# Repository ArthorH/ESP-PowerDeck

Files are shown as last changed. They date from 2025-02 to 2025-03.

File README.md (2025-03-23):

# ESP PowerDeck
Versitale development board for ESP32-S3 microcontroller
PowerDeckRender
## Project Status: **Ongoing**  
**Design** ✅ — **Fabrication** ✅ — **Assembly** ✅ — **Bringup** ⏳ — **Testing** ⏳  
## Key technologies:
&nbsp;&nbsp;&nbsp;&nbsp; &nbsp;&nbsp;&nbsp;&nbsp; &nbsp;&nbsp;&nbsp;&nbsp; &nbsp;&nbsp;&nbsp;&nbsp;
## Who it's for

Want to play with robotics? Maybe you have a cool IoT project in mind? You don't want to hassle with assembling development modules or soldering jumper cables, and jump straight into controlling serious hardware—not just LEDs on a breadboard?


#### Power deck is for you! 
&nbsp;&nbsp;&nbsp;&nbsp; &nbsp;&nbsp;&nbsp;&nbsp;
# Features
- 60W Power delivery input
- High power 5V and 3.3V line outputs
- 3 Channel H-Bridge power output stage with "SafeMode" and to 43W single channel H-Bridge output
- I2C current feedback for H-Bridges
- WS2812 and servo otputs
- Built in UART bridge
- Built in USB 2.0 Hub for ESP32 OTG
- UVLO OVLO protection for barrel jack psu

# Block Diagram:
A

# Usage:
It can drive anything from simple DC motors and Steppers:
izqkav0x

To driving bldc motors using advanced FOC alghoritms:
obraz

Also last but not least IoT projects are also possible:
obraz

# Author
Artem Horiunov
# License 
CERN-OHL-P V2

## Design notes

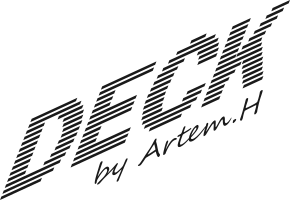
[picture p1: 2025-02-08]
PCB source/Doc/Silkscreen.png

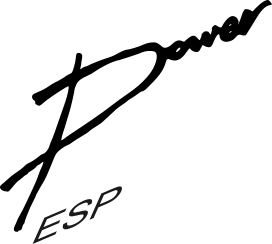
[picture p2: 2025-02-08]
PCB source/Doc/Copper.png

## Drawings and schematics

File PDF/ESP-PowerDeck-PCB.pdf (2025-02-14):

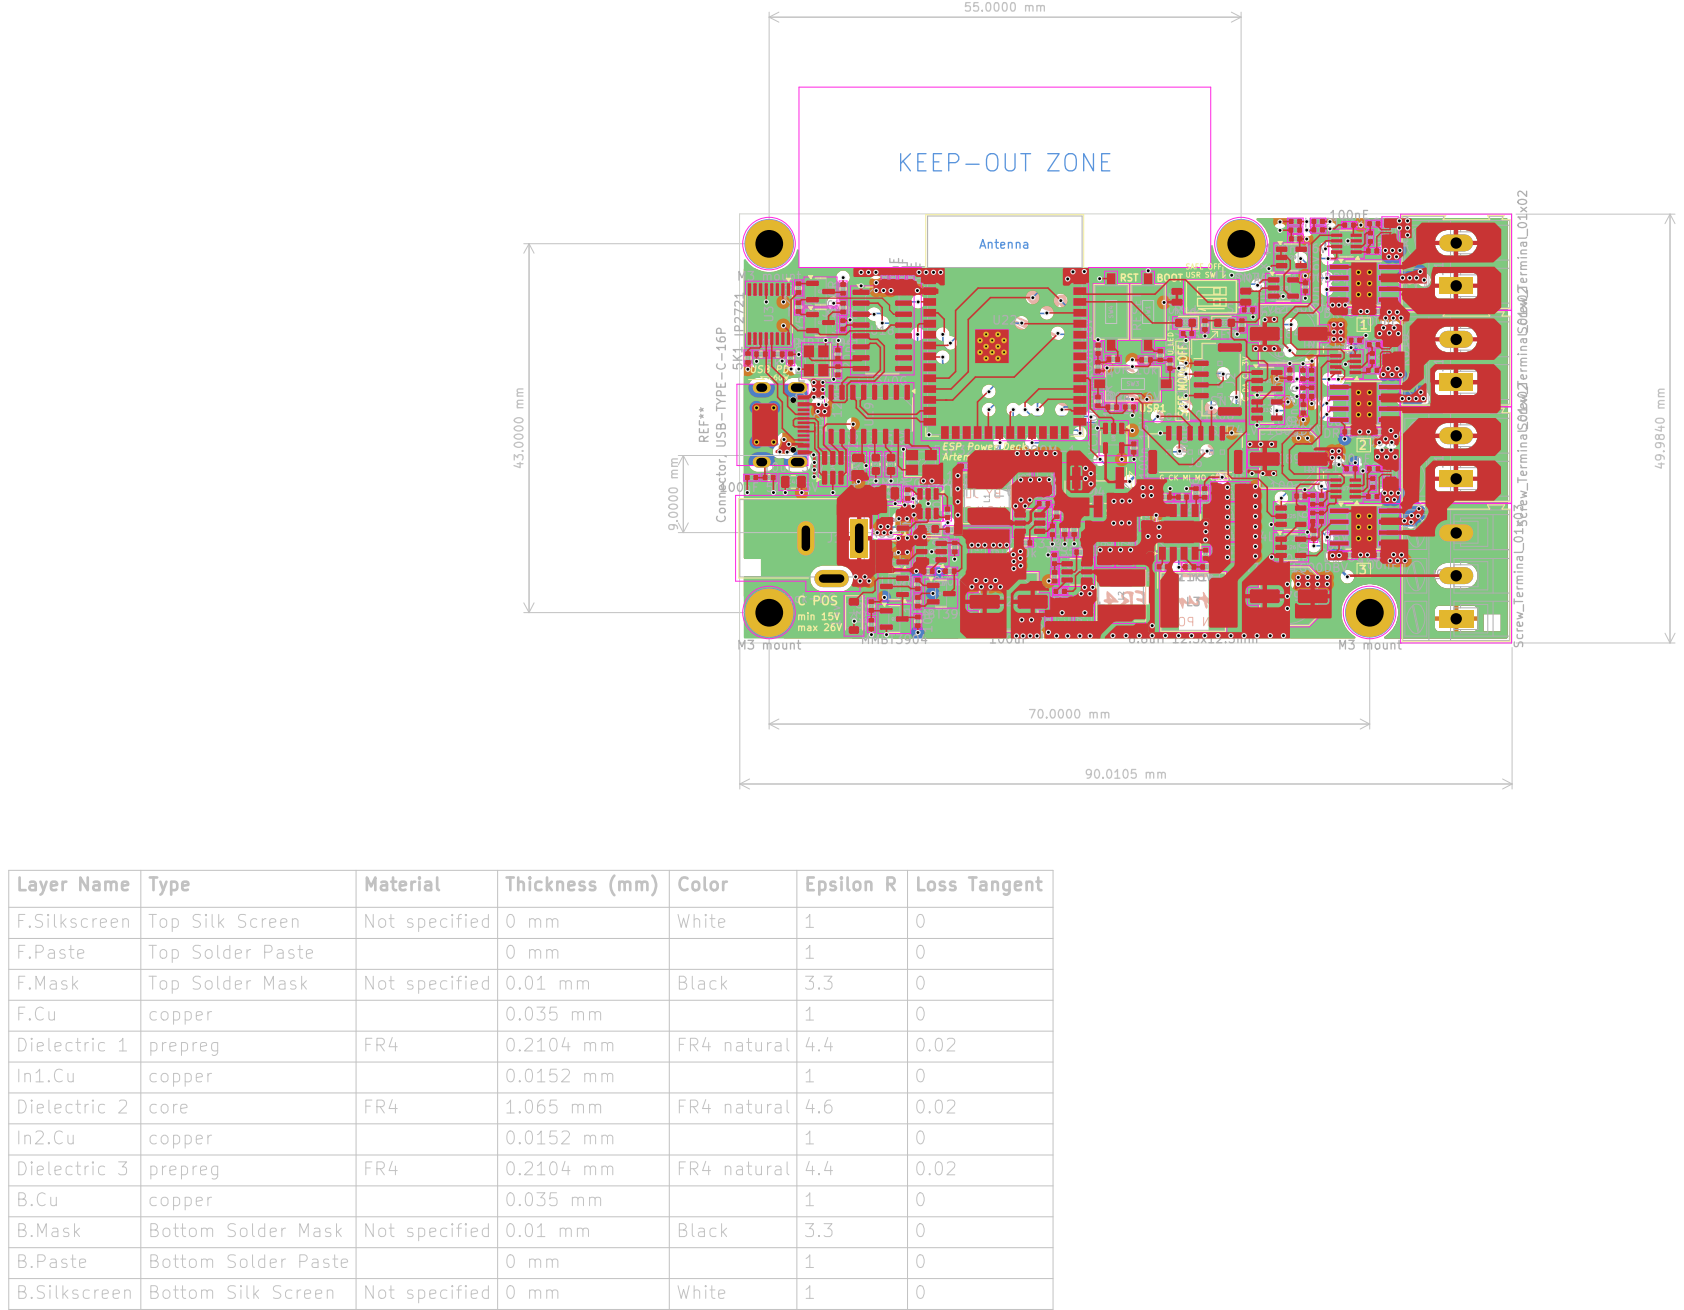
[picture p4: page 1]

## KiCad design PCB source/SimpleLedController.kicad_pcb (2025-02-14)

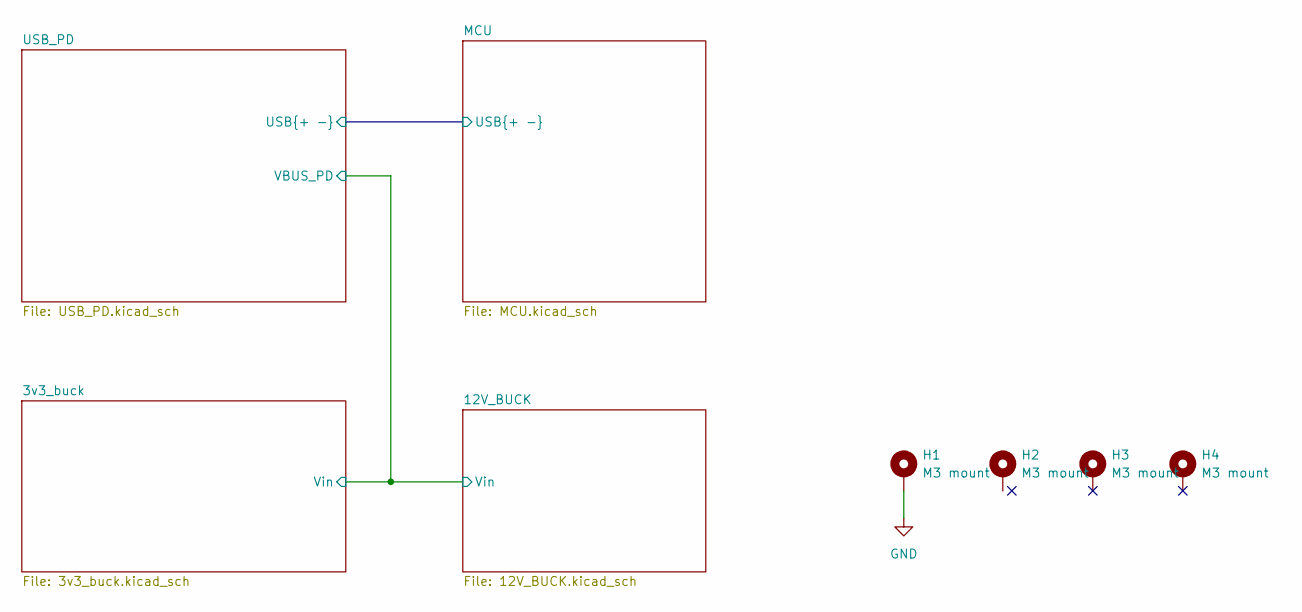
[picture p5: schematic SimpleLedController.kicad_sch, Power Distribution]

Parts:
H1, H2, H3, H4: M3 mount; MountingHole_3.2mm_M3_DIN965_Pad

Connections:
GND: H1.1; also elsewhere on the board

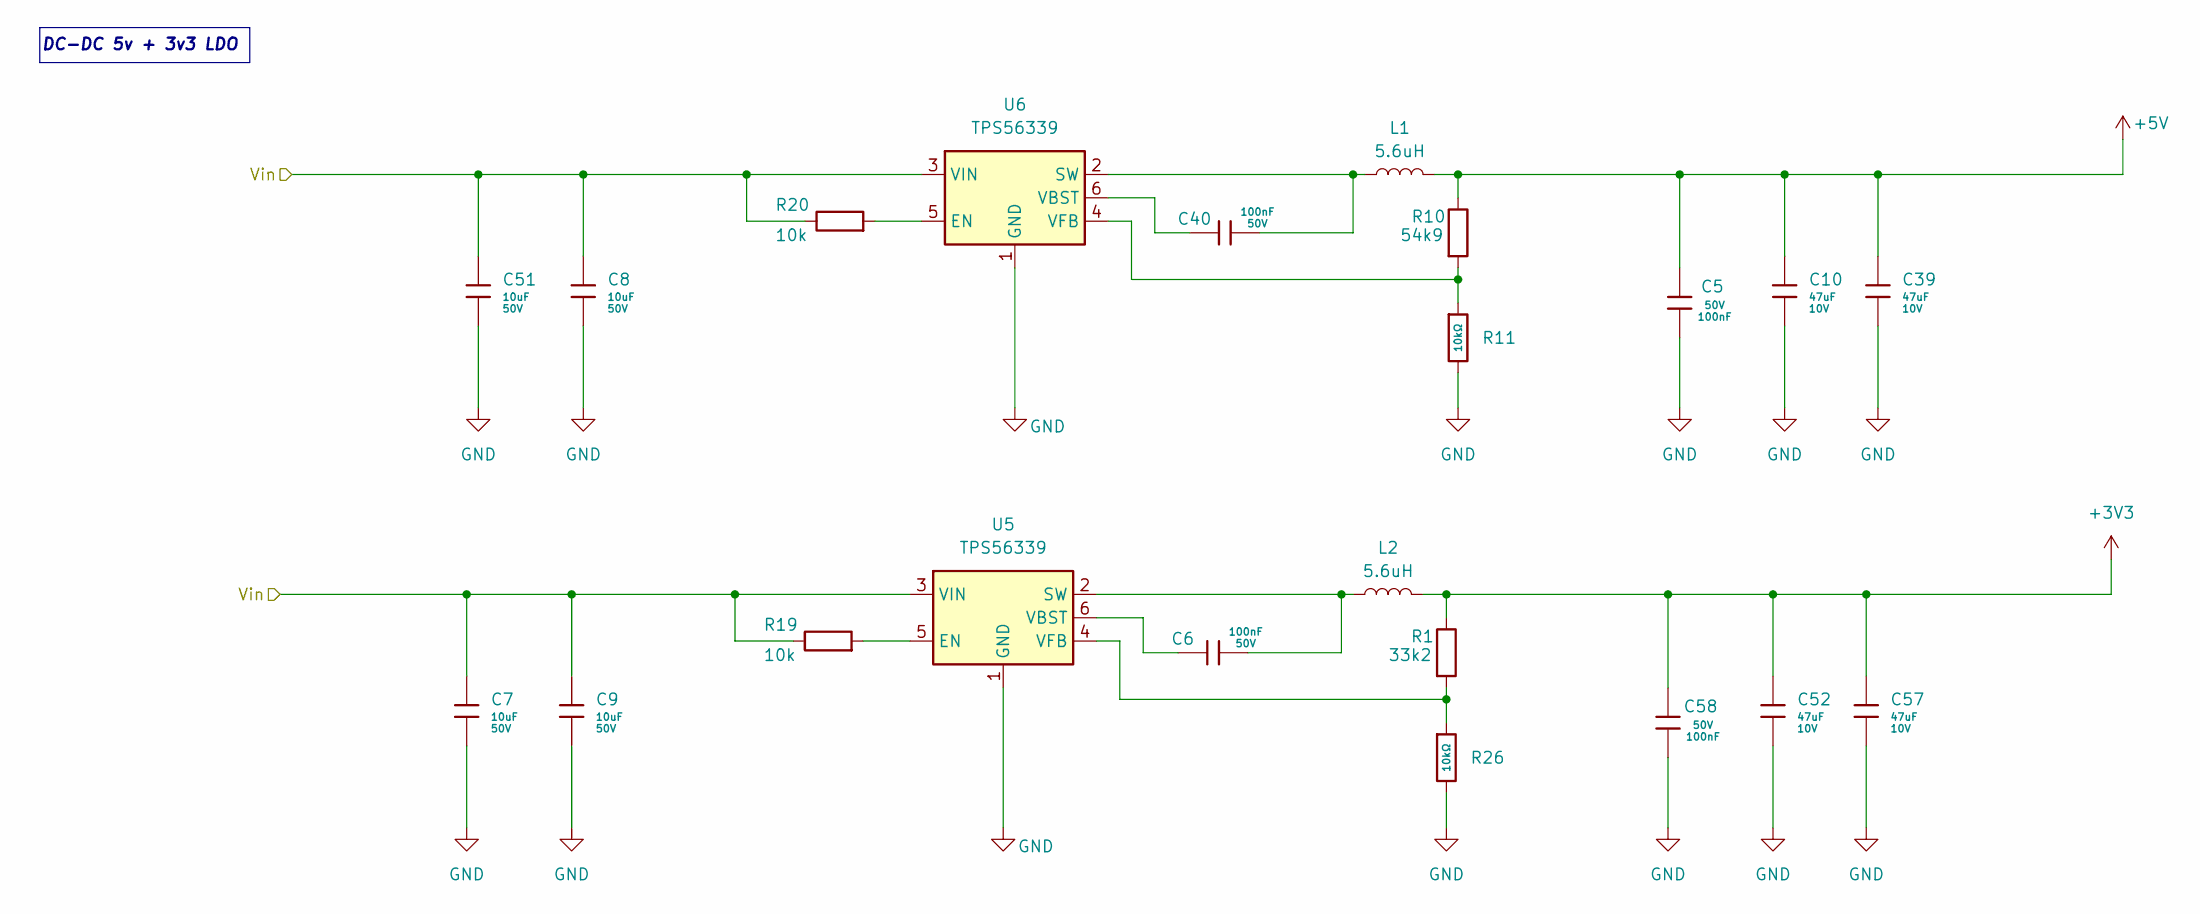
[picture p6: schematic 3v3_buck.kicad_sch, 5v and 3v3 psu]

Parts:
C5, C6, C40, C58: 100nF; C_0402; Voltage Rated 50V; Tolerance ±10%; Part CL05B104KB54PNC; LCSC C307331
C7, C8, C9, C51: 10uF; C_1206; Voltage Rated 50V; Tolerance ±10%; Part CL31A106KBHNNNE; LCSC C13585
C10, C39, C52, C57: 47uF; C_1206; Voltage Rated 10V; Tolerance ±20%; Part CL31A476MPHNNNE; LCSC C96123
L1, L2: 5.6uH; L_Sunlord_MWSA0518S
R1: 33k2; R_0402_1005Metric
R10: 54k9; R_0402_1005Metric
R11, R26: 10kΩ; R_0402; Overload Voltage (Max) 50V; Tolerance ±1%; Part 0402WGF1002TCE; LCSC C25744
R19, R20: 10k; R_0402_1005Metric
U5, U6: TPS56339; SOT-23-6

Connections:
+3V3: C52.1, C57.1, C58.2, L2.2, R1.1; also elsewhere on the board
+5V: C5.2, C10.1, C39.1, L1.2, R10.1; also elsewhere on the board
/USB_PD/VBUS: C7.1, C8.1, C9.1, C51.1, R19.1, R20.1, U5.3 (VIN), U6.3 (VIN); also elsewhere on the board
GND: C5.1, C7.2, C8.2, C9.2, C10.2, C39.2, C51.2, C52.2, C57.2, C58.1, R11.2, R26.2, U5.1 (GND), U6.1 (GND); also elsewhere on the board
unnamed: R19.2, U5.5 (EN)
unnamed: C6.2, L2.1, U5.2 (SW)
unnamed: C6.1, U5.6 (VBST)
unnamed: R1.2, R26.1, U5.4 (VFB)
unnamed: R20.2, U6.5 (EN)
unnamed: C40.2, L1.1, U6.2 (SW)
unnamed: C40.1, U6.6 (VBST)
unnamed: R10.2, R11.1, U6.4 (VFB)

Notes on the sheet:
DC-DC 5v + 3v3 LDO

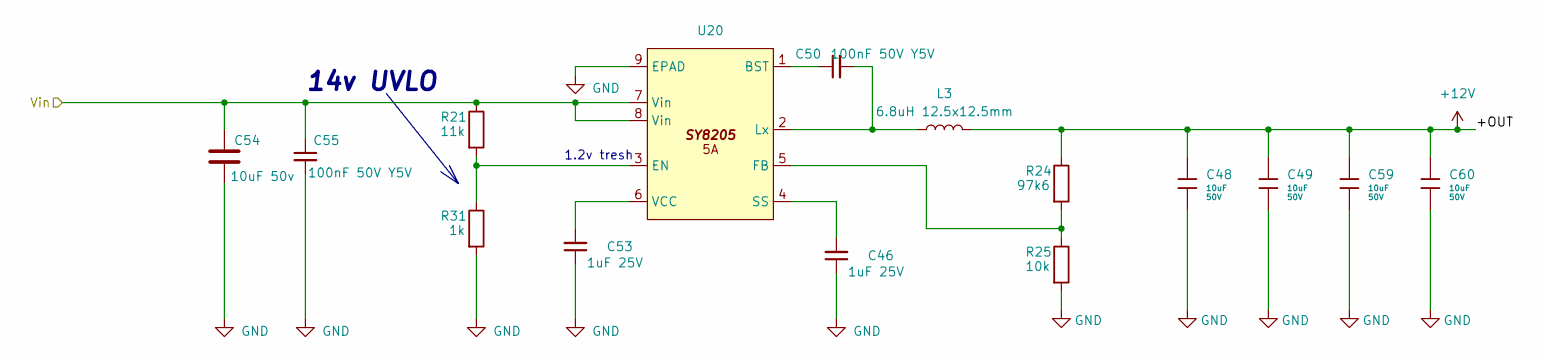
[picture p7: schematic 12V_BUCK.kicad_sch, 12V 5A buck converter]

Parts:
C46, C53: 1uF 25V; C_0402_1005Metric
C48, C49, C59, C60: 10uF; C_1206; Voltage Rated 50V; Tolerance ±10%; Part CL31A106KBHNNNE; LCSC C13585
C50, C55: 100nF 50V Y5V; C_0402_1005Metric
C54: 10uF 50v; C_0805_2012Metric
L3: 6.8uH 12.5x12.5mm; L_AVX_LMLP07A7; MPN YSPI0740-6R8M
R21: 11k; R_0402_1005Metric
R24: 97k6; R_0402_1005Metric
R25: 10k; R_0402_1005Metric
R31: 1k; R_0402_1005Metric
U20: Diodes_SO-8EP

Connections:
+12V: C48.1, C49.1, C59.1, C60.1, L3.2, R24.1; also elsewhere on the board
/USB_PD/VBUS: C54.1, C55.1, R21.1, U20.7 (Vin), U20.8 (Vin); also elsewhere on the board
GND: C46.1, C48.2, C49.2, C53.1, C54.2, C55.2, C59.2, C60.2, R25.2, R31.2, U20.9 (EPAD); also elsewhere on the board
unnamed: C50.1, U20.1 (BST)
unnamed: R21.2, R31.1, U20.3 (EN)
unnamed: R24.2, R25.1, U20.5 (FB)
unnamed: C50.2, L3.1, U20.2 (Lx)
unnamed: C46.2, U20.4 (SS)
unnamed: C53.2, U20.6 (VCC)

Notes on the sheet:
14v UVLO
1.2v tresh

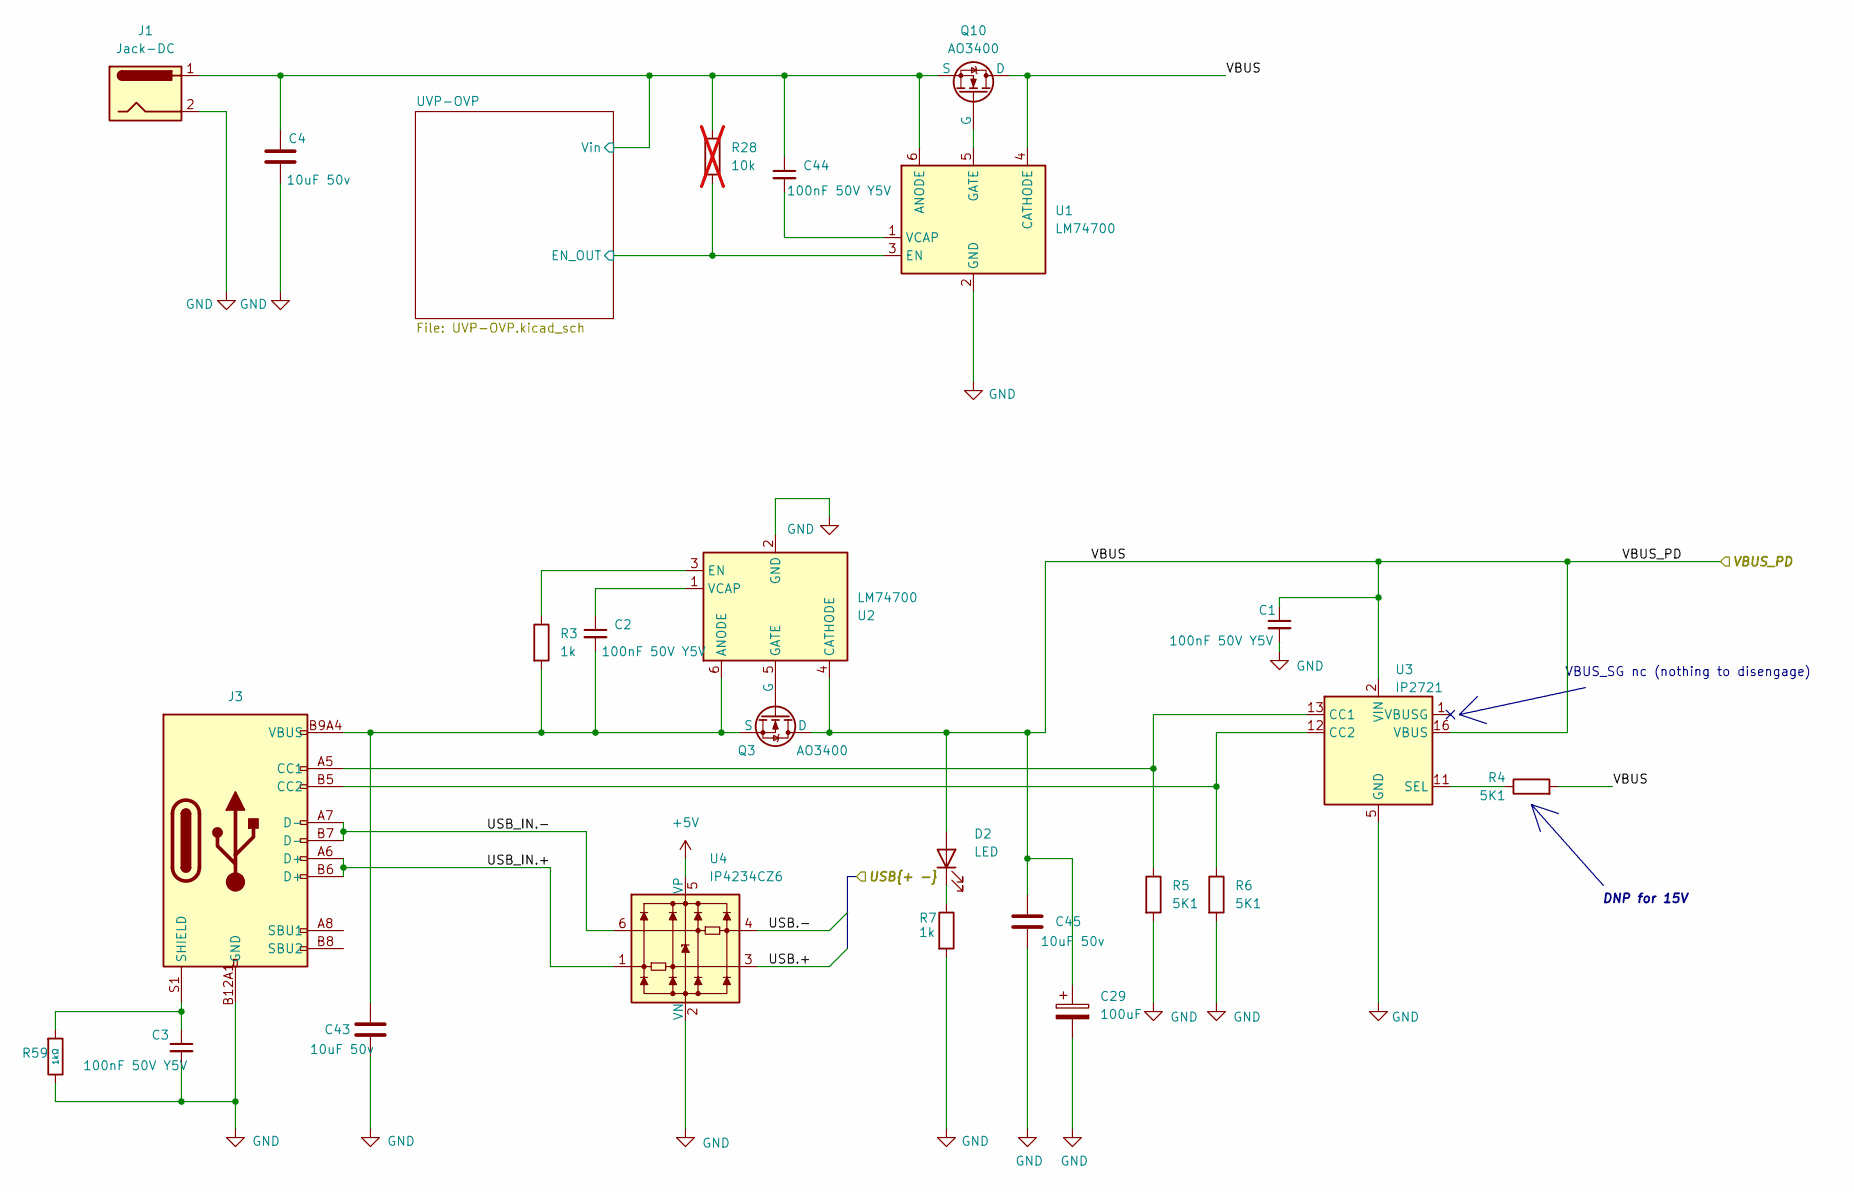
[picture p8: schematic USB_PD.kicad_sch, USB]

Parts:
C1, C2, C3, C44: 100nF 50V Y5V; C_0402_1005Metric
C4, C43, C45: 10uF 50v; C_0805_2012Metric
C29: 100uF; CP_Elec_6.3x5.4
D2: LED; D_0603_1608Metric
J1: Jack-DC; BarrelJack_Kycon_KLDX-0202-xC_Horizontal
J3: Connector, USB-TYPE-C-16P; TYPE-C-SMD_HX-TYPE-C-16PIN; LCSC C2927039
Q3, Q10: AO3400; SOT-23
R3, R7: 1k; R_0402_1005Metric
R4, R5, R6: 5K1; R_0402_1005Metric
R28: 10k; R_0402_1005Metric; not fitted
R59: 1kΩ; R_0402; Overload Voltage (Max) 50V; Tolerance ±1%; Part 0402WGF1001TCE; LCSC C11702
U1, U2: LM74700; SOT-23-6
U3: IP2721; TSSOP-16_4.4x5mm_P0.65mm
U4: IP4234CZ6; SC-74-6_1.55x2.9mm_P0.95mm

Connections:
+5V: U4.5 (VP); also elsewhere on the board
/MCU/USB.+: U4.3; also elsewhere on the board
/MCU/USB.-: U4.4; also elsewhere on the board
/USB_PD/USB_IN.+: J3.A6 (D+), J3.B6 (D+), U4.1
/USB_PD/USB_IN.-: J3.A7 (D-), J3.B7 (D-), U4.6
/USB_PD/UVP-OVP/EN_OUT: R28.2, U1.3 (EN); also elsewhere on the board
/USB_PD/UVP-OVP/Vin: C4.1, C44.1, J1.1, Q10.3 (S), R28.1, U1.6 (ANODE); also elsewhere on the board
/USB_PD/VBUS: C1.1, C29.1, C45.1, D2.2 (A), Q3.2 (D), Q10.2 (D), R4.2, U1.4 (CATHODE), U2.4 (CATHODE), U3.2 (VIN), U3.16 (VBUS); also elsewhere on the board
GND: C1.2, C3.2, C4.2, C29.2, C43.2, C45.2, J1.2, J3.A12B1 (GND), J3.B12A1 (GND), R5.2, R6.2, R7.2, R59.2, U1.2 (GND), U2.2 (GND), U3.5 (GND), U4.2 (VN); also elsewhere on the board
unnamed: D2.1 (K), R7.1
unnamed: J3.A5 (CC1), R5.1, U3.13 (CC1)
unnamed: J3.B5 (CC2), R6.1, U3.12 (CC2)
unnamed: C3.1, J3.S1 (SHIELD), R59.1
unnamed: Q3.1 (G), U2.5 (GATE)
unnamed: C2.2, C43.1, J3.A9B4 (VBUS), J3.B9A4 (VBUS), Q3.3 (S), R3.2, U2.6 (ANODE)
unnamed: Q10.1 (G), U1.5 (GATE)
unnamed: C44.2, U1.1 (VCAP)
unnamed: R3.1, U2.3 (EN)
unnamed: C2.1, U2.1 (VCAP)
unnamed: R4.1, U3.11 (SEL)

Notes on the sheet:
VBUS_SG nc (nothing to disengage)
DNP for 15V

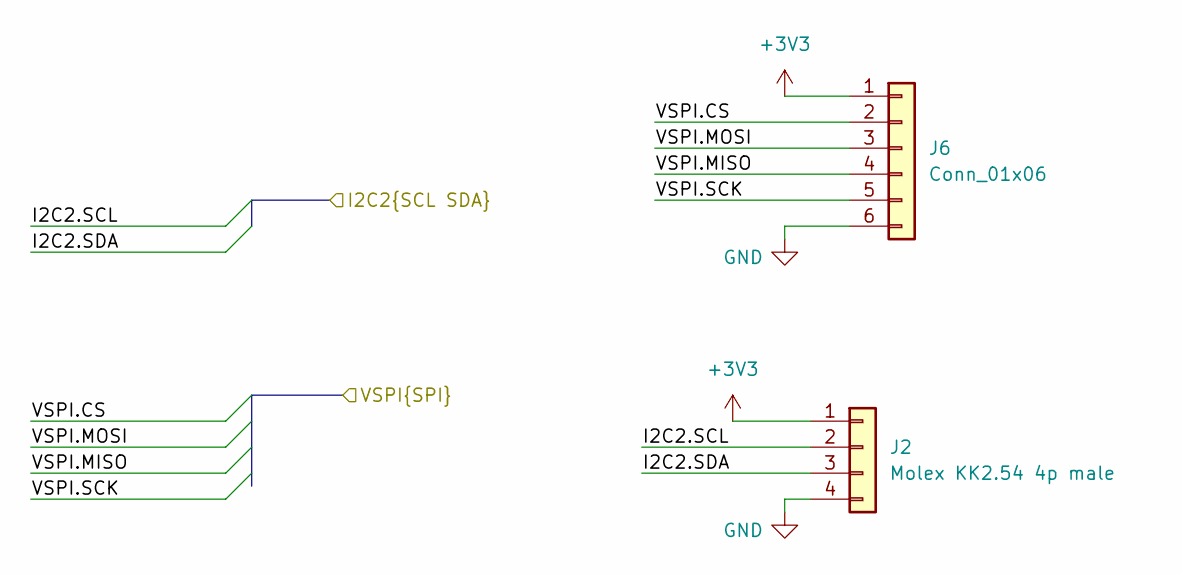
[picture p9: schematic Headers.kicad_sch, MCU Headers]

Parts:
J2: Molex KK2.54 4p male; JST_GH_BM04B-GHS-TBT_1x04-1MP_P1.25mm_Vertical
J6: Conn_01x06; JST_GH_BM06B-GHS-TBT_1x06-1MP_P1.25mm_Vertical

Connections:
+3V3: J2.1, J6.1; also elsewhere on the board
/MCU/ESP32S3/I2C2.SCL: J2.2; also elsewhere on the board
/MCU/ESP32S3/I2C2.SDA: J2.3; also elsewhere on the board
/MCU/ESP32S3/VSPI.CS: J6.2; also elsewhere on the board
/MCU/ESP32S3/VSPI.MISO: J6.4; also elsewhere on the board
/MCU/ESP32S3/VSPI.MOSI: J6.3; also elsewhere on the board
/MCU/ESP32S3/VSPI.SCK: J6.5; also elsewhere on the board
GND: J2.4, J6.6; also elsewhere on the board

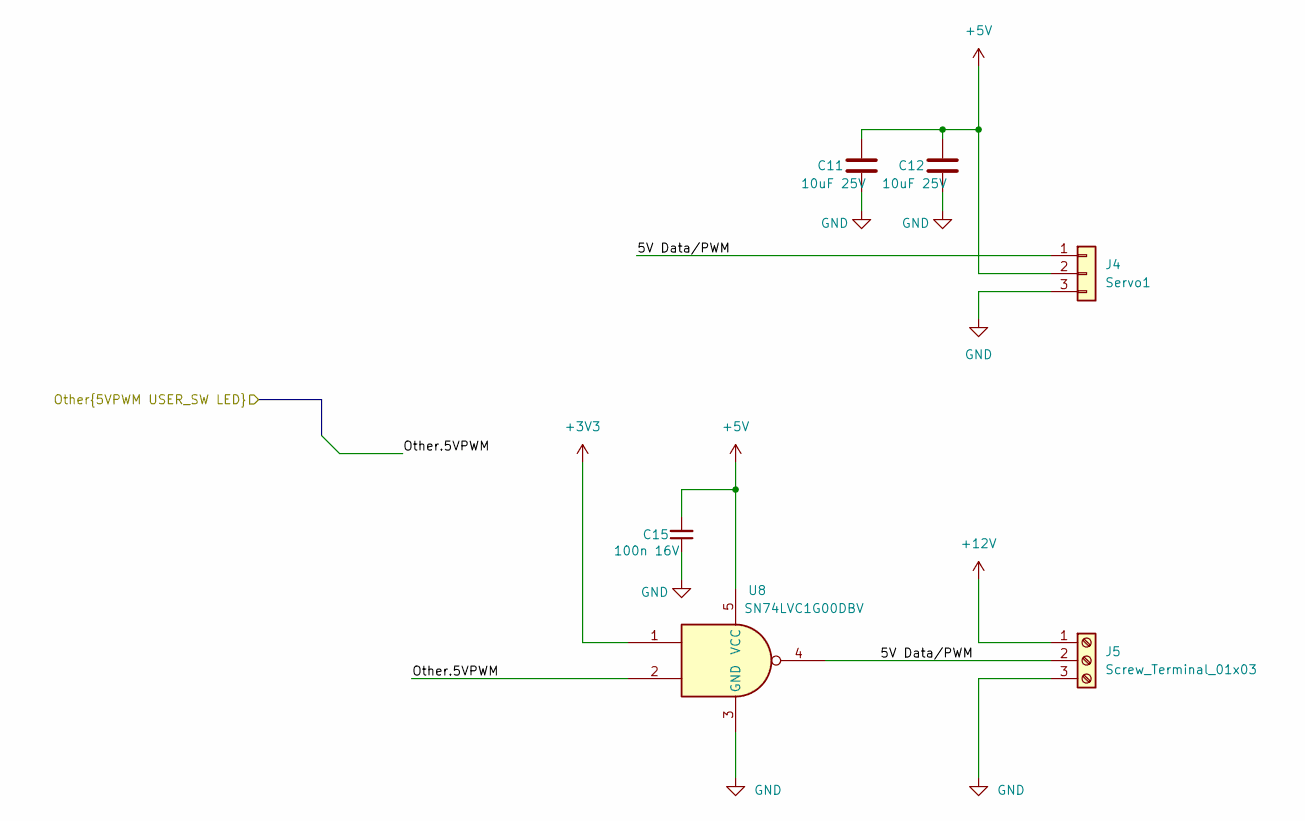
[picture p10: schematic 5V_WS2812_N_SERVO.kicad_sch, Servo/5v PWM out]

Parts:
C11, C12: 10uF 25V; R_0402_1005Metric
C15: 100n 16V; C_0402_1005Metric
J4: Servo1; PinHeader_1x03_P2.54mm_Vertical_SMD_Pin1Left
J5: Screw_Terminal_01x03; TerminalBlock_Altech_AK300-3_P5.00mm
U8: SN74LVC1G00DBV; SOT-23-5

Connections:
+3V3: U8.1; also elsewhere on the board
+5V: C11.1, C12.1, C15.2, J4.2, U8.5 (VCC); also elsewhere on the board
+12V: J5.1; also elsewhere on the board
/MCU/5V WS2812 and Servo/5V Data/PWM: J4.1, J5.2, U8.4
/MCU/5V WS2812 and Servo/Other.5VPWM: U8.2; also elsewhere on the board
GND: C11.2, C12.2, C15.1, J4.3, J5.3, U8.3 (GND); also elsewhere on the board

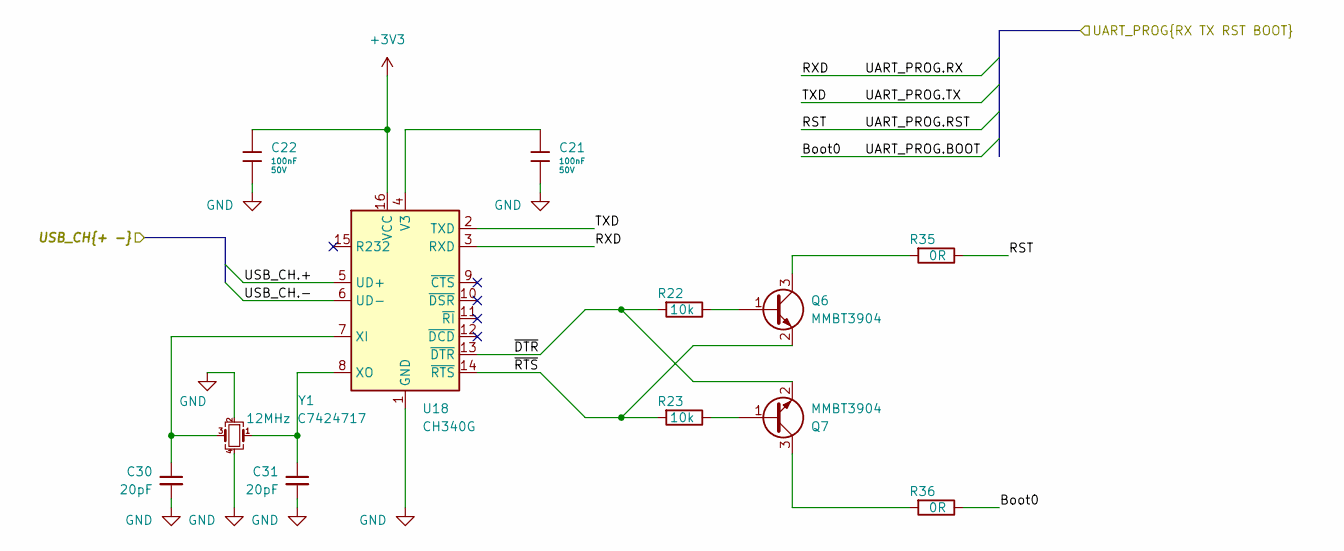
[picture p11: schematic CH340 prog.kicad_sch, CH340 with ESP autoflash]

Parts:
C21, C22: 100nF; C_0402; Voltage Rated 50V; Tolerance ±10%; Part CL05B104KB54PNC; LCSC C307331
C30, C31: 20pF; C_0402_1005Metric
Q6, Q7: MMBT3904; SOT-23
R22, R23: 10k; R_0402_1005Metric
R35, R36: 0R; R_0402_1005Metric
U18: CH340G; SOIC-16_3.9x9.9mm_P1.27mm
Y1: 12MHz C7424717; Crystal_SMD_3225-4Pin_3.2x2.5mm

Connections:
+3V3: C22.1, U18.16 (VCC); also elsewhere on the board
/MCU/CH340 prog/UART_PROG.BOOT: R36.1; also elsewhere on the board
/MCU/CH340 prog/UART_PROG.RST: R35.1; also elsewhere on the board
/MCU/CH340 prog/UART_PROG.RX: U18.3 (RXD); also elsewhere on the board
/MCU/CH340 prog/UART_PROG.TX: U18.2 (TXD); also elsewhere on the board
/MCU/CH340 prog/USB_CH.+: U18.5 (UD+); also elsewhere on the board
/MCU/CH340 prog/USB_CH.-: U18.6 (UD-); also elsewhere on the board
/MCU/CH340 prog/~DTR: Q7.2 (E), R22.2, U18.13 (~DTR)
/MCU/CH340 prog/~RTS: Q6.2 (E), R23.2, U18.14 (~RTS)
GND: C21.2, C22.2, C30.2, C31.2, U18.1 (GND), Y1.2, Y1.4; also elsewhere on the board
unnamed: Q6.1 (B), R22.1
unnamed: Q6.3 (C), R35.2
unnamed: Q7.1 (B), R23.1
unnamed: Q7.3 (C), R36.2
unnamed: C21.1, U18.4 (V3)
unnamed: C30.1, U18.7 (XI), Y1.3
unnamed: C31.1, U18.8 (XO), Y1.1

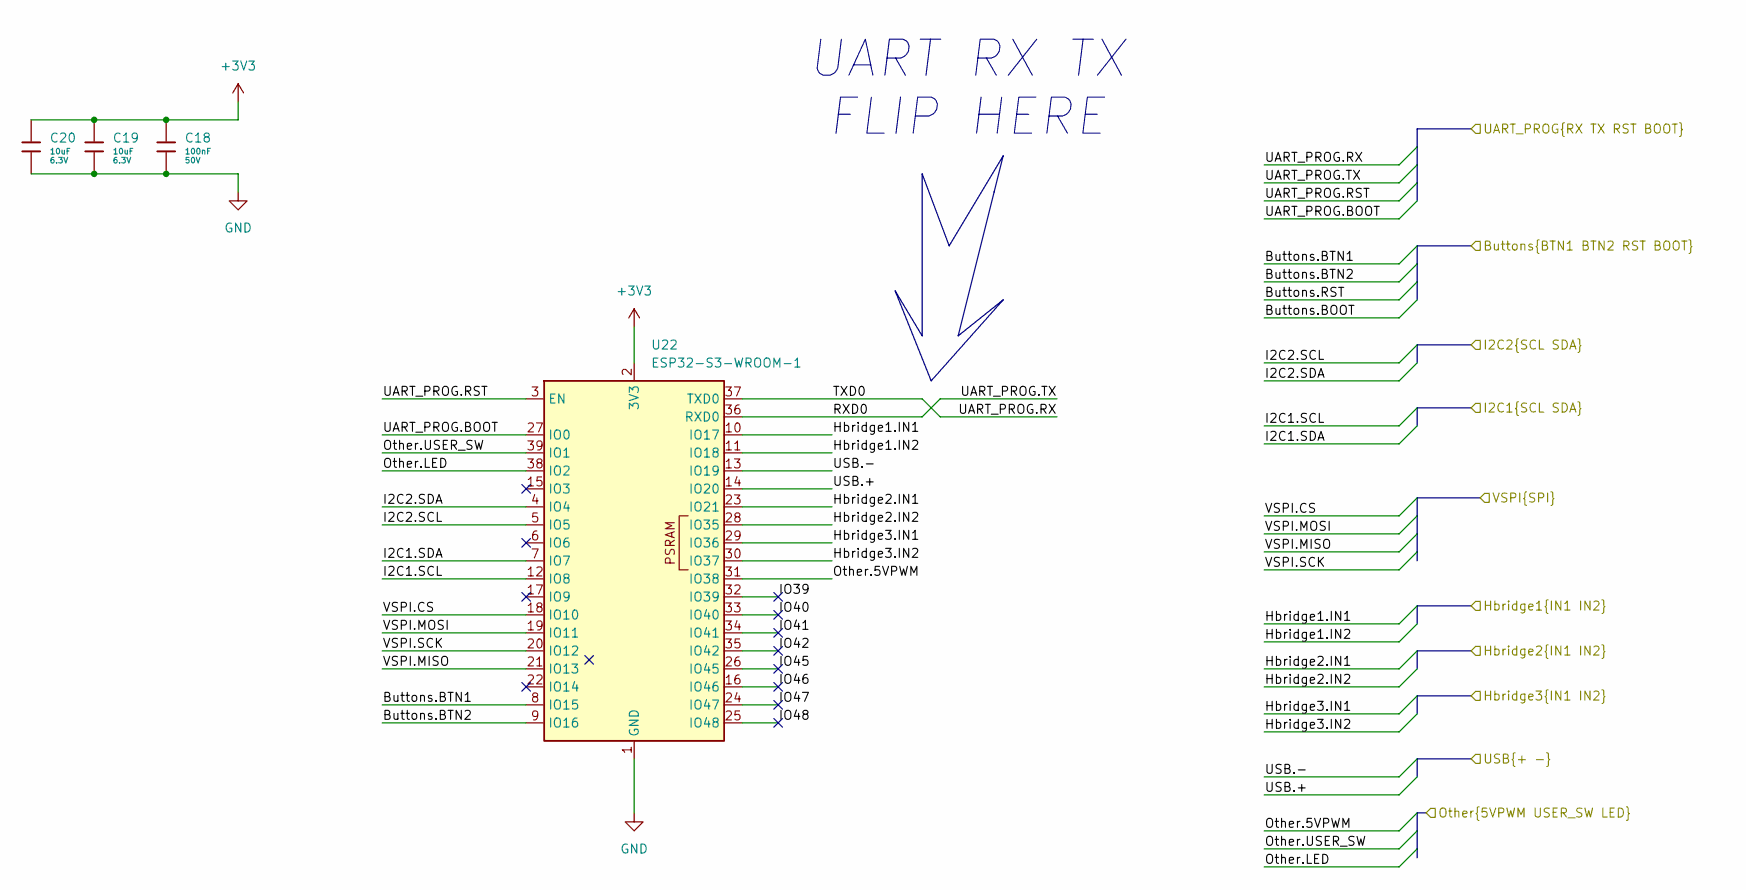
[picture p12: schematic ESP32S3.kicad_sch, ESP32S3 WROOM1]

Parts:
C18: 100nF; C_0402; Voltage Rated 50V; Tolerance ±10%; Part CL05B104KB54PNC; LCSC C307331
C19, C20: 10uF; C_0402; Voltage Rated 6.3V; Tolerance ±20%; Part CL05A106MQ5NUNC; LCSC C15525
U22: ESP32-S3-WROOM-1

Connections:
+3V3: C18.1, C19.1, C20.1, U22.2 (3V3); also elsewhere on the board
/MCU/5V WS2812 and Servo/Other.5VPWM: U22.31 (IO38); also elsewhere on the board
/MCU/5V WS2812 and Servo/Other.LED: U22.38 (IO2); also elsewhere on the board
/MCU/5V WS2812 and Servo/Other.USER_SW: U22.39 (IO1); also elsewhere on the board
/MCU/Buttons/Buttons.BTN1: U22.8 (IO15); also elsewhere on the board
/MCU/Buttons/Buttons.BTN2: U22.9 (IO16)
/MCU/CH340 prog/UART_PROG.BOOT: U22.27 (IO0); also elsewhere on the board
/MCU/CH340 prog/UART_PROG.RST: U22.3 (EN); also elsewhere on the board
/MCU/CH340 prog/UART_PROG.RX: U22.37 (TXD0); also elsewhere on the board
/MCU/CH340 prog/UART_PROG.TX: U22.36 (RXD0); also elsewhere on the board
/MCU/ESP32S3/Hbridge1.IN1: U22.10 (IO17); also elsewhere on the board
/MCU/ESP32S3/Hbridge1.IN2: U22.11 (IO18); also elsewhere on the board
/MCU/ESP32S3/Hbridge2.IN1: U22.23 (IO21); also elsewhere on the board
/MCU/ESP32S3/Hbridge2.IN2: U22.28 (IO35); also elsewhere on the board
/MCU/ESP32S3/Hbridge3.IN1: U22.29 (IO36); also elsewhere on the board
/MCU/ESP32S3/Hbridge3.IN2: U22.30 (IO37); also elsewhere on the board
/MCU/ESP32S3/I2C1.SCL: U22.12 (IO8); also elsewhere on the board
/MCU/ESP32S3/I2C1.SDA: U22.7 (IO7); also elsewhere on the board
/MCU/ESP32S3/I2C2.SCL: U22.5 (IO5); also elsewhere on the board
/MCU/ESP32S3/I2C2.SDA: U22.4 (IO4); also elsewhere on the board
/MCU/ESP32S3/IO39: U22.32 (IO39)
/MCU/ESP32S3/IO40: U22.33 (IO40)
/MCU/ESP32S3/IO41: U22.34 (IO41)
/MCU/ESP32S3/IO42: U22.35 (IO42)
/MCU/ESP32S3/IO45: U22.26 (IO45)
/MCU/ESP32S3/IO46: U22.16 (IO46)
/MCU/ESP32S3/IO47: U22.24 (IO47)
/MCU/ESP32S3/IO48: U22.25 (IO48)
/MCU/ESP32S3/USB.+: U22.14 (IO20); also elsewhere on the board
/MCU/ESP32S3/USB.-: U22.13 (IO19); also elsewhere on the board
/MCU/ESP32S3/VSPI.CS: U22.18 (IO10); also elsewhere on the board
/MCU/ESP32S3/VSPI.MISO: U22.21 (IO13); also elsewhere on the board
/MCU/ESP32S3/VSPI.MOSI: U22.19 (IO11); also elsewhere on the board
/MCU/ESP32S3/VSPI.SCK: U22.20 (IO12); also elsewhere on the board
GND: C18.2, C19.2, C20.2, U22.1 (GND), U22.40 (GND), U22.41 (GND); also elsewhere on the board

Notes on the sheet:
UART RX TX FLIP HERE

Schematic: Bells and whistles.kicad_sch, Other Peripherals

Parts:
D3: Red; D_0603; Part KT-0603R; LCSC C2286
R8: 1kΩ; R_0402; Overload Voltage (Max) 50V; Tolerance ±1%; Part 0402WGF1001TCE; LCSC C11702

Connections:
/MCU/5V WS2812 and Servo/Other.LED: D3.2; also elsewhere on the board
GND: R8.2; also elsewhere on the board
unnamed: D3.1, R8.1

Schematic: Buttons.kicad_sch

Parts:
C13, C16, C17: 100n 16V; C_0402_1005Metric
R9, R15, R16: 10k; R_0402_1005Metric
R13, R17, R18: 100R; R_0402_1005Metric
SW1, SW3, SW4: RESET; SW_Tactile_SPST_NO_Straight_CK_PTS636Sx25SMTRLFS; MPN TSB008A2530A; LCSC C2888954

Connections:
+3V3: R9.1, R15.1, R16.1; also elsewhere on the board
/MCU/Buttons/Buttons.BOOT: C16.2, R15.2, R17.1
/MCU/Buttons/Buttons.BTN1: C13.2, R9.2, R13.1; also elsewhere on the board
/MCU/Buttons/Buttons.RST: C17.2, R16.2, R18.1
GND: C13.1, C16.1, C17.1, SW1.2, SW3.2, SW4.2; also elsewhere on the board
unnamed: R13.2, SW1.1
unnamed: R17.2, SW3.1
unnamed: R18.2, SW4.1

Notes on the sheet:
USER button2 is no more. Use WIFI :)
Note: if autoflash works as intended then remove boot 1 and replace as user btn

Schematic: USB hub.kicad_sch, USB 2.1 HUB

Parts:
C32, C33: 10uF 6.3V; C_0603_1608Metric
U19: SL2.1A; SO-16_3.9x9.9mm_P1.27mm
Y2: 12MHz C7424717; Crystal_SMD_3225-4Pin_3.2x2.5mm

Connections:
+5V: U19.11 (VDD5); also elsewhere on the board
/MCU/CH340 prog/USB_CH.+: U19.8 (DP1); also elsewhere on the board
/MCU/CH340 prog/USB_CH.-: U19.7 (DM1); also elsewhere on the board
/MCU/ESP32S3/USB.+: U19.6 (DP2); also elsewhere on the board
/MCU/ESP32S3/USB.-: U19.5 (DM2); also elsewhere on the board
/MCU/USB.+: U19.10 (DP); also elsewhere on the board
/MCU/USB.-: U19.9 (DM); also elsewhere on the board
GND: C32.1, C33.1, U19.12 (GND), Y2.2, Y2.4; also elsewhere on the board
unnamed: C32.2, U19.14 (VDD18)
unnamed: C33.2, U19.13 (VDD33)
unnamed: U19.16 (XIN), Y2.3
unnamed: U19.15 (XOUT), Y2.1

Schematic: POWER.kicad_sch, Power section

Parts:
D1: LED; LED_0603_1608Metric
R12: 10kΩ; R_0402; Overload Voltage (Max) 50V; Tolerance ±1%; Part 0402WGF1002TCE; LCSC C25744
R47: 10k; R_0402_1005Metric
R48: 680R; R_0402_1005Metric
S1: DIP Switch x 2; SW-SMD_218-2LPSTRF; Current Rating 25mA; Voltage Rating 24V; Part 218-2LPSTR; LCSC C2961921

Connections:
+3V3: S1.3, S1.4; also elsewhere on the board
/MCU/5V WS2812 and Servo/Other.USER_SW: R12.1, S1.1; also elsewhere on the board
/MCU/POWER SECTION/DRV1/~SAFE OPERATION: D1.2 (A), R47.1, S1.2; also elsewhere on the board
GND: R12.2, R47.2, R48.2; also elsewhere on the board
unnamed: D1.1 (K), R48.1

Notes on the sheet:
SAFE MODE OFF

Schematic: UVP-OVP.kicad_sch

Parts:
D4: 14v; D_SOD-123
Q4: MMBT3906; SOT-23
Q5, Q9: MMBT3904; SOT-23
R39: 1k5; R_0402_1005Metric
R40: 39k; R_0402_1005Metric
R41, R42, R43: 10k; R_0402_1005Metric
R44: 1k; R_0402_1005Metric

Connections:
/USB_PD/UVP-OVP/EN_OUT: Q4.3 (C), R43.1; also elsewhere on the board
/USB_PD/UVP-OVP/Vin: R39.1, R40.1, R41.1; also elsewhere on the board
GND: D4.2 (A), Q9.2 (E), R43.2, R44.2; also elsewhere on the board
unnamed: D4.1 (K), Q5.2 (E)
unnamed: Q4.1 (B), R42.1
unnamed: Q4.2 (E), R39.2
unnamed: Q5.1 (B), Q9.3 (C), R41.2
unnamed: Q5.3 (C), R42.2
unnamed: Q9.1 (B), R40.2, R44.1

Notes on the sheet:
BRAND NEW!
Artem H
3 transistor all-in-one OVP UVP

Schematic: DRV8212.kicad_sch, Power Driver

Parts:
C23, C26: 100nF; C_0402; Voltage Rated 50V; Tolerance ±10%; Part CL05B104KB54PNC; LCSC C307331
C79: 100uF; CP_Elec_6.3x5.4
C80: 100nF; C_0402_1005Metric
C81, C82, C83: 100n 16V; C_0402_1005Metric
J12: Screw_Terminal_01x02; TerminalBlock_Altech_AK300-2_P5.00mm
R2, R30, R53, R54: 0Ω; R_0402; Overload Voltage (Max) 50V; Tolerance ±1%; Part 0402WGF0000TCE; LCSC C17168; not fitted
R34, R45: 10Ω; R_0402; Overload Voltage (Max) 50V; Tolerance ±1%; Part 0402WGF100JTCE; LCSC C25077
R50: R010; R_0805; Overload Voltage (Max) 150V; Tolerance ±1%; Part 0805W8F200KT5E; LCSC C163089
U7: INA219AxDCN; SOT-23-8
U24: DRV8870DDA; Texas_HTSOP-8-1EP_3.9x4.9mm_P1.27mm_EP2.95x4.9mm_Mask2.4x3.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
U25, U26: SN74LVC1G00DBV; SOT-23-5

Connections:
+3V3: C23.1, C81.2, C82.2, C83.2, R53.1, R54.1, U7.4 (VS), U24.4 (VREF), U25.5 (VCC), U26.5 (VCC); also elsewhere on the board
+12V: C79.1, C80.2, U24.5 (VM); also elsewhere on the board
/MCU/ESP32S3/Hbridge3.IN1: U24.3 (IN1); also elsewhere on the board
/MCU/ESP32S3/Hbridge3.IN2: U25.1; also elsewhere on the board
/MCU/ESP32S3/I2C1.SCL: U7.5 (SCL); also elsewhere on the board
/MCU/ESP32S3/I2C1.SDA: U7.6 (SDA); also elsewhere on the board
/MCU/POWER SECTION/DRV1/~SAFE OPERATION: U25.2; also elsewhere on the board
/MCU/POWER SECTION/DRV3/IN22: U24.2 (IN2), U26.4
GND: C23.2, C79.2, C80.1, C81.1, C82.1, C83.1, R2.2, R30.2, R45.2, R50.2, U7.3 (GND), U24.1 (GND), U24.9 (GND), U25.3 (GND), U26.3 (GND); also elsewhere on the board
unnamed: J12.1, U24.6 (OUT1)
unnamed: J12.2, U24.8 (OUT2)
unnamed: R2.1, R54.2, U7.7 (A0)
unnamed: R30.1, R53.2, U7.8 (A1)
unnamed: C26.1, R34.1, U7.1 (IN+)
unnamed: C26.2, R45.1, U7.2 (IN-)
unnamed: R34.2, R50.1, U24.7 (ISEN)
unnamed: U25.4, U26.1, U26.2

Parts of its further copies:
C24, C25, C27, C28: 100nF; C_0402; Voltage Rated 50V; Tolerance ±10%; Part CL05B104KB54PNC; LCSC C307331
C84, C89: 100uF; CP_Elec_6.3x5.4
C85, C90: 100nF; C_0402_1005Metric
C86, C87, C88, C91, C92, C93: 100n 16V; C_0402_1005Metric
J13, J14: Screw_Terminal_01x02; TerminalBlock_Altech_AK300-2_P5.00mm
R27, R29, R32, R33, R55, R56, R57, R58: 0Ω; R_0402; Overload Voltage (Max) 50V; Tolerance ±1%; Part 0402WGF0000TCE; LCSC C17168; not fitted
R37, R38, R46, R49: 10Ω; R_0402; Overload Voltage (Max) 50V; Tolerance ±1%; Part 0402WGF100JTCE; LCSC C25077
R51, R52: R010; R_0805; Overload Voltage (Max) 150V; Tolerance ±1%; Part 0805W8F200KT5E; LCSC C163089
U9, U10: INA219AxDCN; SOT-23-8
U27, U30: DRV8870DDA; Texas_HTSOP-8-1EP_3.9x4.9mm_P1.27mm_EP2.95x4.9mm_Mask2.4x3.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
U28, U29, U31, U32: SN74LVC1G00DBV; SOT-23-5

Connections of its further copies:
+3V3: C24.1, C25.1, C86.2, C87.2, C88.2, C91.2, C92.2, C93.2, R55.1, R56.1, R57.1, R58.1, U9.4 (VS), U10.4 (VS), U27.4 (VREF), U28.5 (VCC), U29.5 (VCC), U30.4 (VREF), U31.5 (VCC), U32.5 (VCC); also elsewhere on the board
+12V: C84.1, C85.2, C89.1, C90.2, U27.5 (VM), U30.5 (VM); also elsewhere on the board
/MCU/ESP32S3/Hbridge1.IN1: U27.3 (IN1); also elsewhere on the board
/MCU/ESP32S3/Hbridge1.IN2: U28.1; also elsewhere on the board
/MCU/ESP32S3/Hbridge2.IN1: U30.3 (IN1); also elsewhere on the board
/MCU/ESP32S3/Hbridge2.IN2: U31.1; also elsewhere on the board
/MCU/ESP32S3/I2C1.SCL: U9.5 (SCL), U10.5 (SCL); also elsewhere on the board
/MCU/ESP32S3/I2C1.SDA: U9.6 (SDA), U10.6 (SDA); also elsewhere on the board
/MCU/POWER SECTION/DRV1/IN22: U27.2 (IN2), U29.4
/MCU/POWER SECTION/DRV1/~SAFE OPERATION: U28.2, U31.2; also elsewhere on the board
/MCU/POWER SECTION/DRV2/IN22: U30.2 (IN2), U32.4
GND: C24.2, C25.2, C84.2, C85.1, C86.1, C87.1, C88.1, C89.2, C90.1, C91.1, C92.1, C93.1, R27.2, R29.2, R32.2, R33.2, R46.2, R49.2, R51.2, R52.2, U9.3 (GND), U10.3 (GND), U27.1 (GND), U27.9 (GND), U28.3 (GND), U29.3 (GND), U30.1 (GND), U30.9 (GND), U31.3 (GND), U32.3 (GND); also elsewhere on the board
unnamed: J13.1, U27.6 (OUT1)
unnamed: J13.2, U27.8 (OUT2)
unnamed: J14.1, U30.6 (OUT1)
unnamed: J14.2, U30.8 (OUT2)
unnamed: R27.1, R56.2, U9.7 (A0)
unnamed: R32.1, R55.2, U9.8 (A1)
unnamed: C27.1, R37.1, U9.1 (IN+)
unnamed: C27.2, R46.1, U9.2 (IN-)
unnamed: R29.1, R58.2, U10.7 (A0)
unnamed: R33.1, R57.2, U10.8 (A1)
unnamed: C28.1, R38.1, U10.1 (IN+)
unnamed: C28.2, R49.1, U10.2 (IN-)
unnamed: R37.2, R51.1, U27.7 (ISEN)
unnamed: U28.4, U29.1, U29.2
unnamed: R38.2, R52.1, U30.7 (ISEN)
unnamed: U31.4, U32.1, U32.2

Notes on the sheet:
expecting up to 6A
NOTE: Safe mode prevents user from shorting h-bridge VCC to GND while using RGB led strip. It effectively switches h-bridge to half bridge so only IN1 could be operated
FVM025ADA101M0654
0.010R (60mOhm) with 0.2W power package
40mV full scale
Polarity in safe mode operation

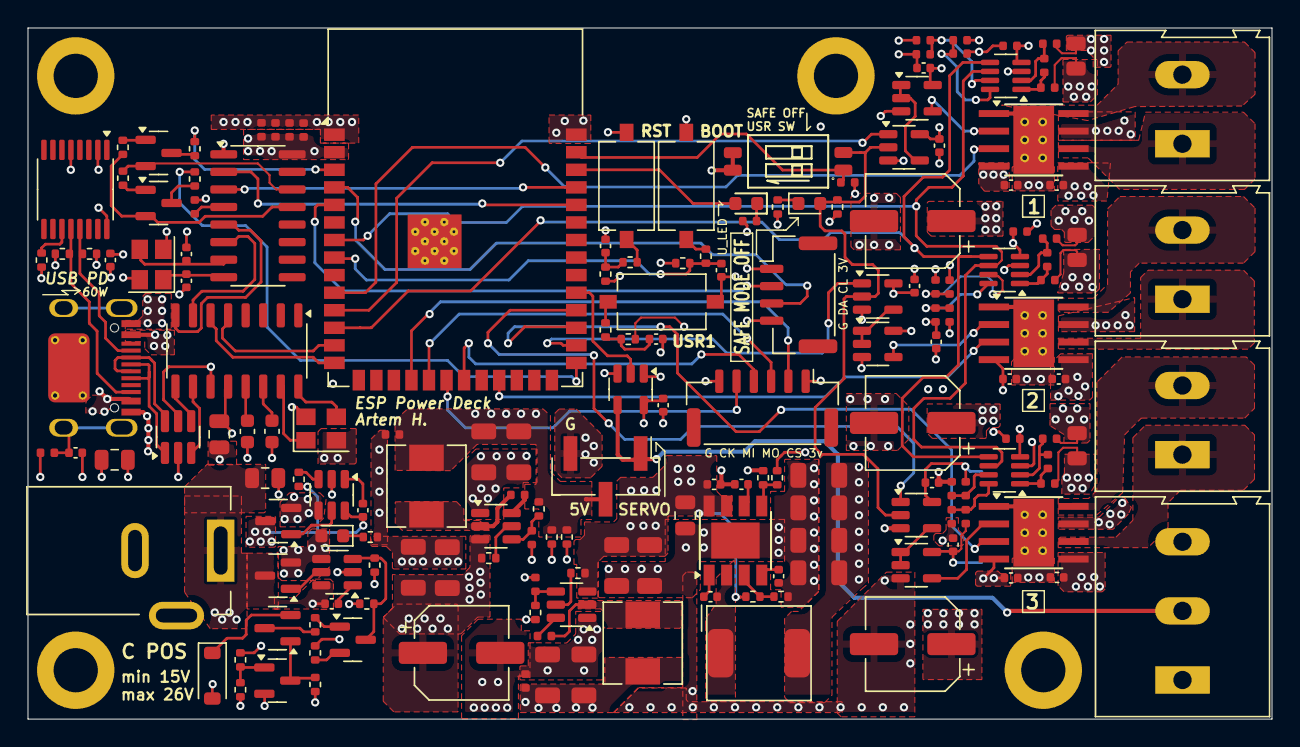
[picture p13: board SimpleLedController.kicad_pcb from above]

Board: 4 copper layers, 90.0 x 50.0 mm, 179 parts (0 on the bottom side), 117 nets.

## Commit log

2025-02-08 Finish Schematic and component placement
    [12V_BUCK.kicad_sch, 3v3_buck.kicad_sch, 5V_WS2812_N_SERVO.kicad_sch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]
2025-02-08 Pack to hardware folder
    [12V_BUCK.kicad_sch, 3v3_buck.kicad_sch, 5V_WS2812_N_SERVO.kicad_sch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]
2025-02-10 Finish PCB
    [5V_WS2812_N_SERVO.kicad_sch, Bells and whistles.kicad_sch, ESP32S3.kicad_sch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]
2025-02-10 Fix INA layout
    [DRV8212.kicad_sch, SimpleLedController.kicad_pcb]
2025-02-12 Add BOM+CPL
    [DRV8212.kicad_sch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]
2025-02-12 Prepare to production (DFM ok)
    [SimpleLedController-CuBottom.gbr, SimpleLedController-CuIn1.gbr, SimpleLedController-CuIn2.gbr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]
2025-02-14 Add Documentation and minor tweaks
    [12V_BUCK.kicad_sch, 3v3_buck.kicad_sch, 5V_WS2812_N_SERVO.kicad_sch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]
2025-02-14 Remove boardhouse designators
    [SimpleLedController.kicad_pcb]
2025-02-14 Do file cleanup
    [SimpleLedController-CuBottom.gbr, SimpleLedController-CuIn1.gbr, SimpleLedController-CuIn2.gbr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]
